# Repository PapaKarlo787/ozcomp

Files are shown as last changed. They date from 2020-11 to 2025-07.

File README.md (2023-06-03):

OzComp
======

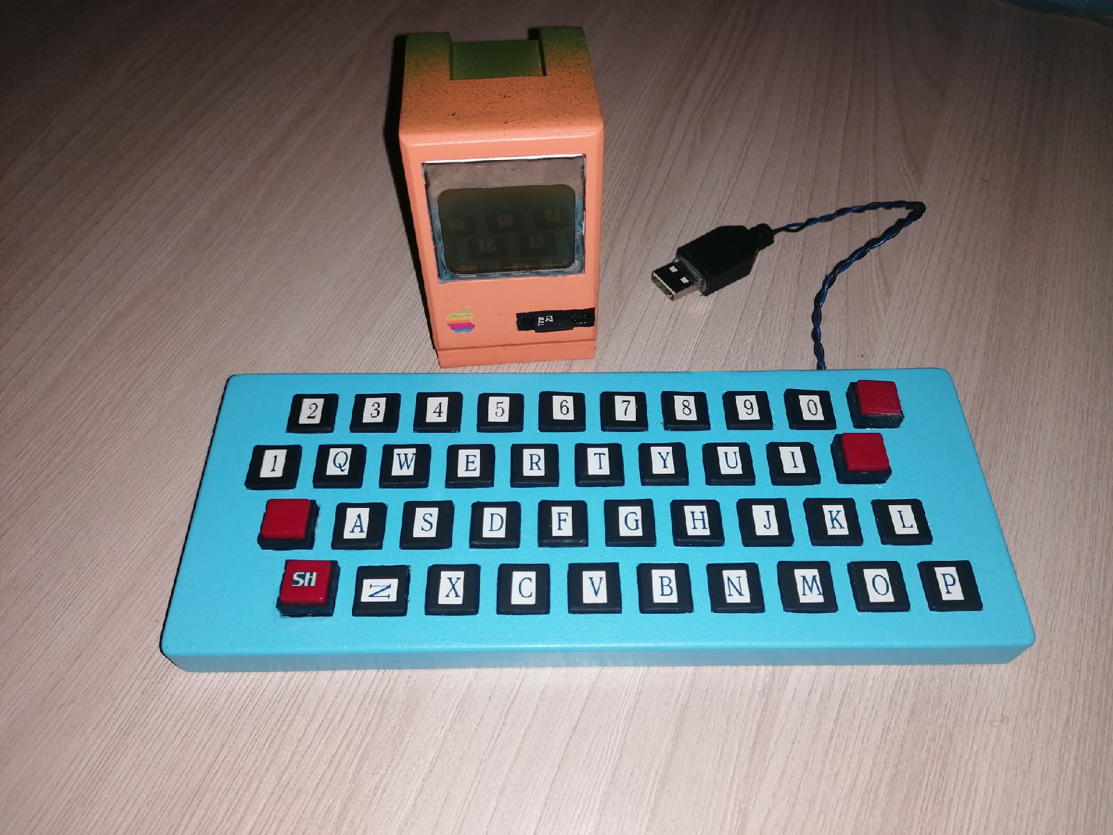
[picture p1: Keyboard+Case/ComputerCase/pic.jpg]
title


### Общее описание

Мы создаем компьютер на базе Arduino с удобными инструкциями, которые позволяют просто общаться с устройствами,
не используя их интерфейсы, не зная ничего о их протоколах и интерфейсах, что сокращает размер исходного кода.
Так же наш проект расширяет возможности Arduino. Теперь ей доступно около 2 Гб (не больше) оперативной памяти,
которая представлена в виде FLASH-памяти на SD карте. Так же имеется теоретическая (пока нет утилит) возможность,
не прибегая к стороннему программированию (программатор, компьютер для загрузки прошивки и т.д.), писать программы,
которые будут работать на нашем компьютере. Помимо прочего, наш проект устраняет скорый износ внутренней FLASH-памяти
(например при частой смене программного обеспечения) и последующую негодность платы. Это происходит за счет наличия внешнего подключения SD карты.

Ниже дано краткое описание системы команд, регистров и архитектуры в целом.
+ По 16 регистров с именами R0-R15 для плавающей арифметики и для целых чисел.
+ Системные регистры в количестве 16 штук, сейчас используются 3 - для указателя на инструкцию, указателя на вершину стека и для флагов состояния.
+ Операции для чисел с плавающей запятой это арифметические, стековые и операции копирования (MOV), их имена предворяются знаком F (FADD, FMOV).
+ Все регистры 32-битные.

### Таблица распиновки
|Пин Arduino	| Пин устройства	|	Название устройства
|-:				|:-:				|:-
D2				| RST				|	Часы
D3				| CLK				|	Клавиатура
D4				| MOSI				|	Экран
D5				| DC				|	Экран
D6				| CE				|	Экран
D7				| RST				|	Экран
D8				| DATA				|	Клавиатура
D9				| CLK				|	Экран
D10				| CS				|	SD
D11				| MOSI				|	SD
D12				| MISO				|	SD
D13				| CLK				|	SD
A0				| DAT				|	Часы
A1				| R					|	RGB
A2				| CLK				|	Часы
A3				| +					|	Пьезо
A4				| G					|	RGB
A5				| B					|	RGB
A6				| C1				|	mini-jack
A7				| C2				|	mini-jack

### Память и системные регистры

+ Память реализована как SD-карта (в эмуляторе файл 'memory'). Программа стартует с нулевого байта.
+ SP это внутренний указатель на вершину стека, устанавливается в начале программы в значение равное объему памяти на SD карте.
+ IP это внутренний указатель на текущую инструкцию.
+ FLAGS это внутренний регистр состояния, состоит из 16 битов устанавливаемых автоматически при выполнении инструкций и 16 битов устанавливаемых
программно для задания состояния компьютеру.

#### Биты регистра флагов

|Номер	|Обозначение| Назначение
|-:		|:-:		|:-
0		| E			| Результат целочисленной арифметики дал значение 0
1		| L			| Результат целочисленной арифметики дал значение < 0
2		| G			| Результат целочисленной арифметики дал значение > 0
3		| I			| Отрисовка графических примитивов перетерла значение на экране
4		| Z			| Результат плавающей арифметики дал значение 0
5		| B			| Результат плавающей арифметики дал значение < 0
6		| A			| Результат плавающей арифметики дал значение > 0
7		| NI		| Отрисовка графических примитивов не перетерла значение на экране
8-15	| N/A		| Зарезервировано
16		| COLOR		| Задает цвет отрисовки графики
17		| RGBSOUND	| Подсвечивать светодиодами музыку 
18-31	| N/A		| Зарезервировано

### Экран

Экран - монохромный и имеет разрешение 84*48 пикселя, это 6 рядов по 84 колонки.
Каждый зажженый пиксель в колонке n от левого верхнего угла последовательно -
слева направо, сверху вниз, означает установленный бит сверху вниз n-го байта в памяти экрана.
Экран не позволяет узнать содержимое своей памяти, поэтому она хранится в памяти Arduino. 

### Клавиатура

Компьютер запускается только при наличии подключенной AT-совместимой клавиатуры (PS/2).

### Звуки

Звуковой источник - пьезо-пищалка, которая установлена на 17 пин Arduino.
Аудио код состоит из количества пар 16-битных чисел, частоты пищания и задержки.
Реально задержки нет, поскольку сигнал генерируется отдельным таймером Arduino.

### Обозначения

+ R - регистр
+ C - константа
+ L - метка
+ N/A - нет аргументов
+ M - ячейка памяти, запись вида [L, R1, R2, N \in {1, 2, 4}], где формула адреса такова L+R1+R2*N - слагаемые могут отсутствовать, синтаксически отделенные запятыми.

### Арифметические операции

|Название 	| Аргументы |	Описание
|-:			|:-:		|:-
ADD 		| R/(R,C)	| 	Сложение
SUB 		| R/(R,C)	| 	Вычитание
MUL 		| R/(R,C)	| 	Умножение
DIV 		| R/(R,C)	| 	Деление
MOD		 	| R/(R,C)	| 	Остаток от деления
POW			| R/(R,C)	| 	Возведение в степень
CMP			| R/(R,C)	| 	Изменить флаги вычитанием
TEST		| R			| 	Изменить флаги сравнением с нулем

### Логические операции

|Название 	| Аргументы |	Описание
|-:			|:-:		|:-
AND 		| R/(R,C)	|	Побитовое И целых частей операндов
OR  		| R/(R,C)	|	Побитовое ИЛИ целых частей операндов
XOR 		| R/(R,C)	|	Побитовое исключающее ИЛИ целых частей операндов
SHR 		| R/(R,C)	|	Битовый сдвиг вправо
SHL 		| R/(R,C)	|	Битовый сдвиг влево

***Общий пример для этих групп команд.***

+ ADD R0, R1
+ ADD R0, 1

### Переходы

|Название 			| Аргументы |	Описание
|-:					|:-:		|:-
JMP					| L			| 	Безусловный переход
J{E,G,L,I,A,B,Z,...}| L			| 	Условный переход по E, G, L
LOOP				| L			| 	Условный переход пока R14 больше 0
CALL				| L			| 	Безусловный переход с сохранением IP в стек 
RET					| N/A		| 	Извлечение IP из стека

***Общий пример для этой группы команд.***

+ JNE my_label
+ CALL my_func
+ RET

### Работа со стеком

|Название 	| Аргументы |	Описание
|-:			|:-:		|:-
PUSH		| R 		|	Положить на стек
POP			| R			|	Снять со стека
FPUSH		| R			|	Положить на стек флоатовское значение
FPOP		| R			|	Снять со стека флоатовское значение

***Примеры***

+ PUSH R0
+ FPOP R1

### Экран, клавиатура и динамик

|Название 	| Аргументы |	Описание
|-:			|:-:		|:-
FPRINT 		| (R,L) 	| 	Печать числа с плавающей запятой
LPRINT 		| (R,L) 	| 	Печать нуль-терминированной строки
PRINT		| (R,L) 	| 	Печать целого числа
SCUR		| R/R, C/C 	| 	Установка курсора на позицию X, Y
SEND		| (R,C)		| 	Отправка байта на экран в текущую позицию курсора
DRAW		| L			| 	Отправить 504 байта в память экрана из памяти с адреса L
GKEY		| N/A		| 	Получить символ клавиатуры в регистре R15, 0 если нет
SCOL  		| C 		| 	Установить цвет рисуемого изображения (0 или не 0 для монохромного экрана)
PLAY  		| L 		| 	Начать циклическое проигрывание музыки
NPLAY 		| N/A		| 	Завершить проигрывание музыки
RGB 		| R/R/R		| 	Установить цвет светодиодов
RGB 		| C/C/C		| 	Установить цвет светодиодов
MLS 		| N/A		| 	Узнать количество милисекунд, пройденных с запуска, в R12
MCS 		| N/A		| 	Узнать количество микросекунд, пройденных с запуска, в R12
RPIX 		| R/(R,C)	| 	Реверс нескольких подряд идущих столбцов экрана

***Примеры***

+ PRINT my_str
+ IPRINT R0
+ SETC R0, R5
+ SETC 10, 20
+ SEND R0 (<256)
+ SEND 85
+ GKEY

### Макрокоманды MCASM

|Название 	| Аргументы 	|	Описание
|-:			|:-:			|:-
DD			| C1, C2, ...	|	Создать несколько 32-битных чисел
DW			| C1, C2, ...	|	Создать несколько 16-битных чисел
DB			| C1, C2, ...	|	Создать несколько 8-битных чисел, (строки тоже)
DF			| C1, C2, ...	|	Создать несколько 32-битных чисел с плавающей запятой
TIMES 		| CMD ARGS  N 	|	Повторить команду CMD N раз

***Примеры***

+ DD -3, 100500, 0xffffffff
+ DB 10, 12, 255, "HELLO WORLD!"
+ DF 3.1415926535, 2.718281828
+ TIMES CALL INC 10

### Другие

|Название 	| Аргументы 	|	Описание
|-:			|:-:			|:-
MOV 		| R/(R,C,M),M/R | 	Перемещение данных во float
MOVB		| R/M,M/R 		|	Перемещение байтов в ячейки памяти
INT			| R				|	Округление
DELAY		| (R,C)			|	Задержка в милисекундах
RND			| N/A			| 	Случайное целое в промежутке [0, 1024], результат в R13
ICVTF 		| R/R 			| 	Конвертация float в int
FCVTI 		| R/R 			| 	Конвертация int в float
GTM 		| R/R/R			| 	Получить время RTC
STM 		| (R/R/R,C/C/C)	| 	Установить время RTC
MZER 		| (R,C)/(C,C)	| 	Занулить фиксированное количество байт по указателю

***Примеры***

+ MOV [my_var], R0
+ MOV R0, [my_var, R1]
+ INT R0
+ DELAY R1
+ DELAY 100
+ RND

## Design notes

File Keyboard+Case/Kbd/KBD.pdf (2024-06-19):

Лист1

Страница 1

Q ES W F1 E F2 R F3 T F4 Y F5 U F6 I F7 O F8 P F9
q TB w | e | r | t | y | u | i ( o ) p BS
A 1 S 2 D 3 F 4 G 5 H 6 J 7 K 8 L 9 ` 0 a ! s @ d # f $ g % h ^ j & k * l ↑ ~ PS Z [ X ] C \ V ; B ' N - M = , DL . PU / PD
z { x } c | v : b “ n _ m + < | > ↓ ? →
Shift Ctrl Alt | ___ | Alt Ctrl Caps ENT

Q ES W F1 E F2 R F3 T F4 Y F5 U F6 I F7 O F8 P F9
q TB w | e | r | t | y | u | i ( o ) p BS
A 1 S 2 D 3 F 4 G 5 H 6 J 7 K 8 L 9 ` 0 a ! s @ d # f $ g % h ^ j & k * l ↑ ~ PS Z [ X ] C \ V ; B ' N - M = , DL . PU / PD
z { x } c | v : b “ n _ m + < | > ↓ ? →
Shift Ctrl Alt | ___ | Alt Ctrl Caps ENT

Q ES W F1 E F2 R F3 T F4 Y F5 U F6 I F7 O F8 P F9
q TB w | e | r | t | y | u | i ( o ) p BS
A 1 S 2 D 3 F 4 G 5 H 6 J 7 K 8 L 9 ` 0 a ! s @ d # f $ g % h ^ j & k * l ↑ ~ PS Z [ X ] C \ V ; B ' N - M = , DL . PU / PD
z { x } c | v : b “ n _ m + < | > ↓ ? →
Shift Ctrl Alt | ___ | Alt Ctrl Caps ENT

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

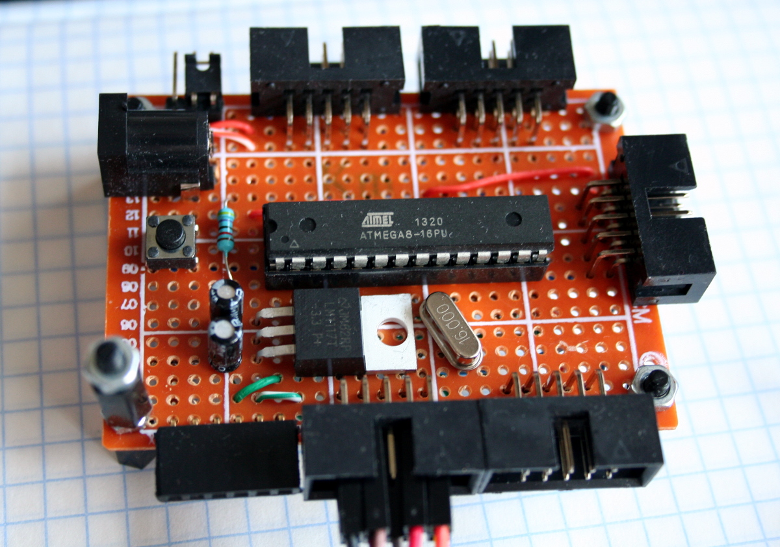
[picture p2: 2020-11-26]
docs/ATmega8 + PCD8544_ работа с графическим дисплеем от телефонов Nokia 5110_3310_files/atmega8.jpg

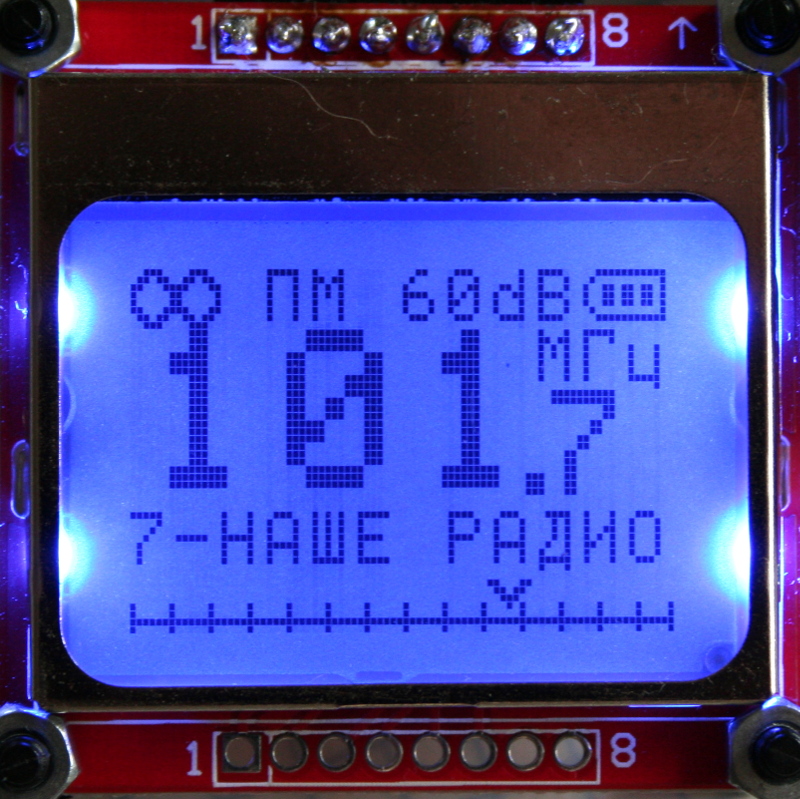
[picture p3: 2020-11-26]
docs/ATmega8 + PCD8544_ работа с графическим дисплеем от телефонов Nokia 5110_3310_files/cover1.jpg

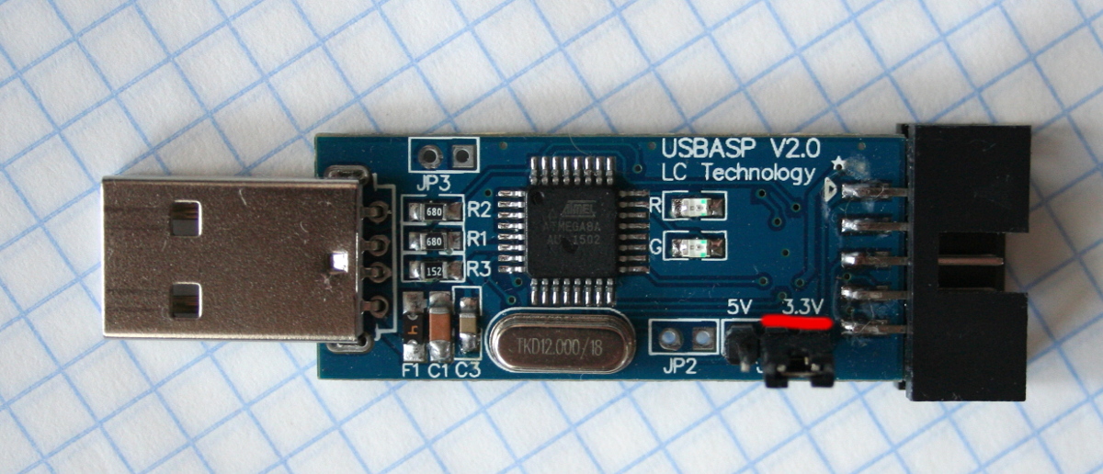
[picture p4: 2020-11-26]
docs/ATmega8 + PCD8544_ работа с графическим дисплеем от телефонов Nokia 5110_3310_files/usbasp.jpg

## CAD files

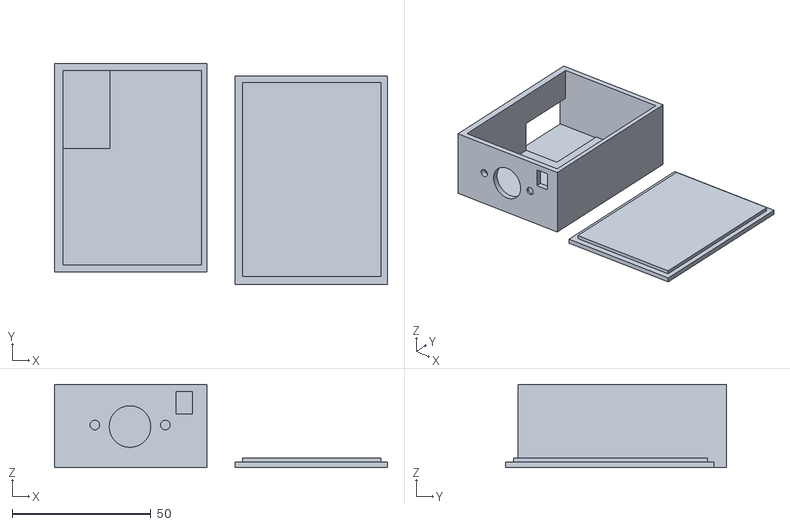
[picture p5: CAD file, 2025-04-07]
Keyboard+Case/CompExtension case.stl
120.0 x 79.5 x 30.0

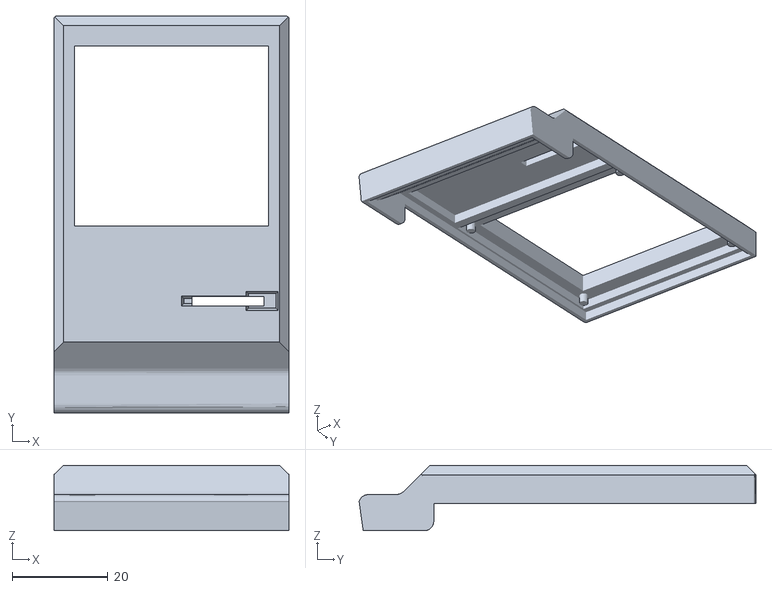
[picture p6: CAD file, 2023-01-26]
Keyboard+Case/ComputerCase/Крышка.stl
49.0 x 82.7 x 13.6

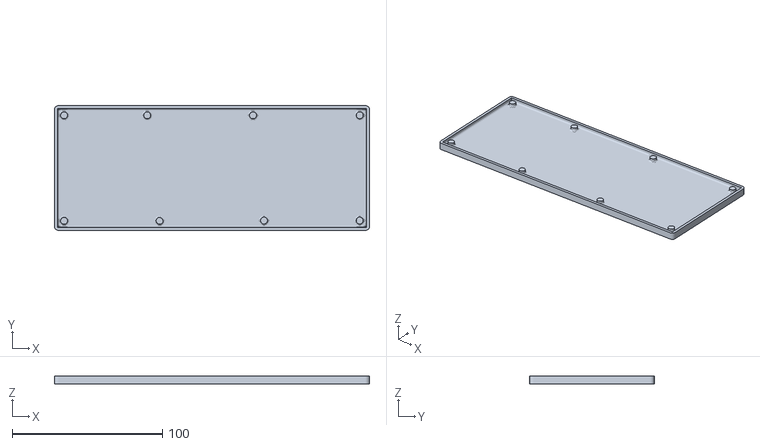
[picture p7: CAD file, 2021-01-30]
Keyboard+Case/KeyboardCase/K-n2.stl
209.5 x 82.9 x 5.10

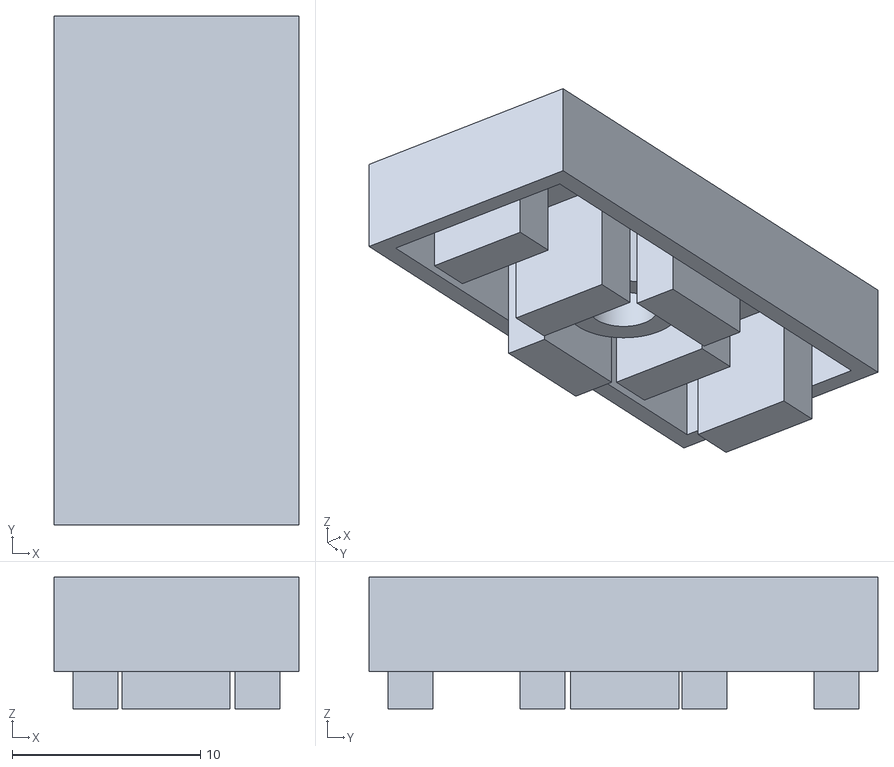
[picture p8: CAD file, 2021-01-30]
Keyboard+Case/KeyboardCase/Keycaps/keycap-long.stl
13.0 x 27.0 x 7.00

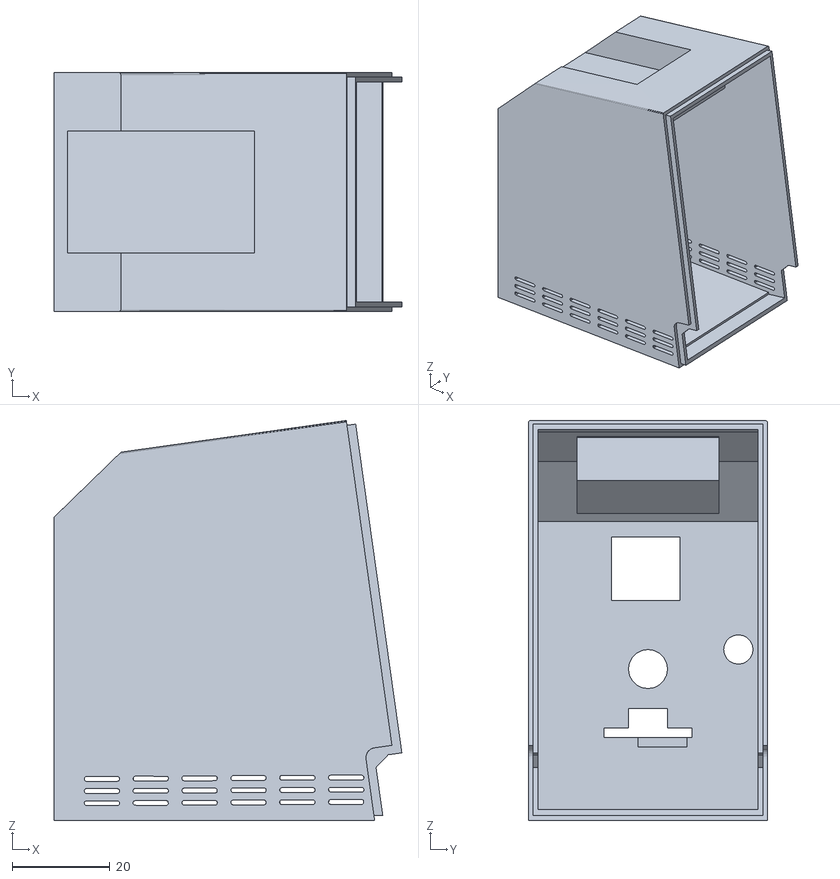
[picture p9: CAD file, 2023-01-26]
Keyboard+Case/ComputerCase/Корпус.stl
71.2 x 49.0 x 81.9

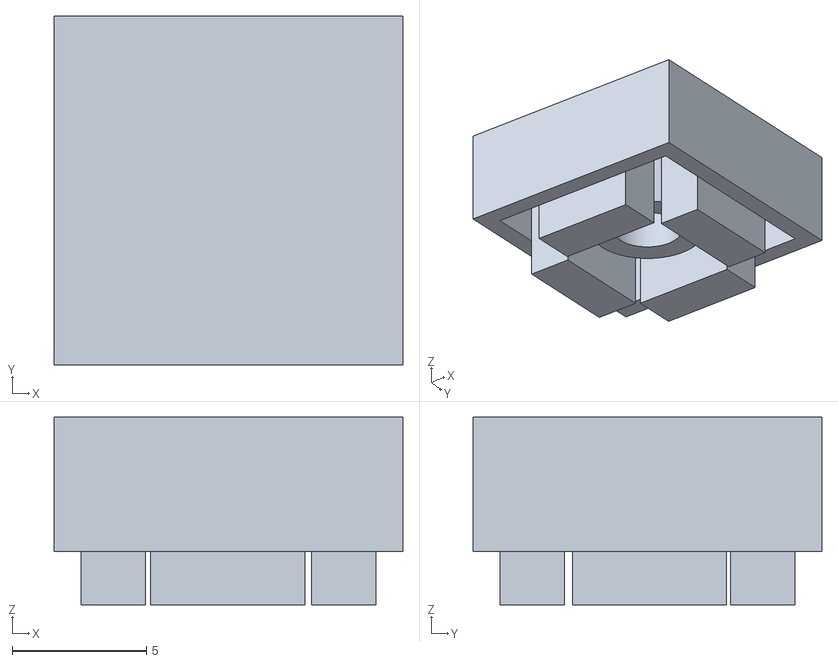
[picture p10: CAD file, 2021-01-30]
Keyboard+Case/KeyboardCase/Keycaps/keycap.stl
13.0 x 13.0 x 7.00

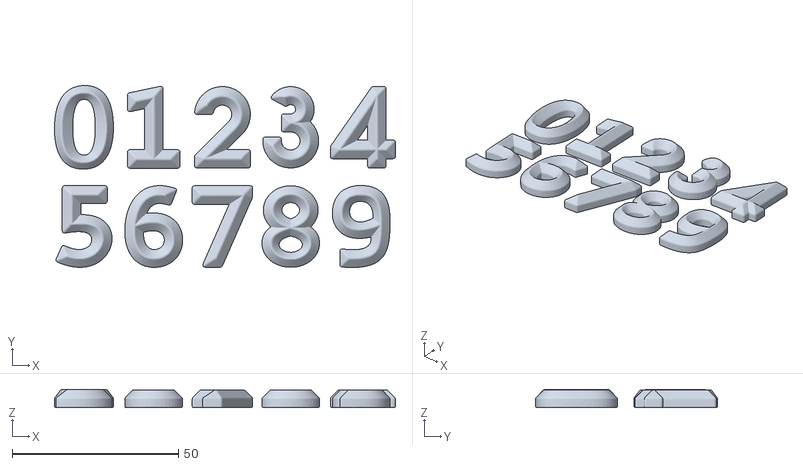
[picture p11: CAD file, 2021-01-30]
Keyboard+Case/KeyboardCase/numbers.stl
102.5 x 54.7 x 5.41

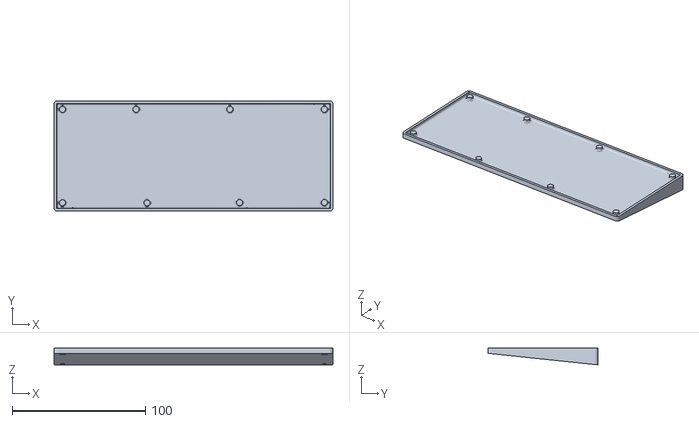
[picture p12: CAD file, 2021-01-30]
Keyboard+Case/KeyboardCase/K-n1.stl
209.5 x 82.9 x 12.6

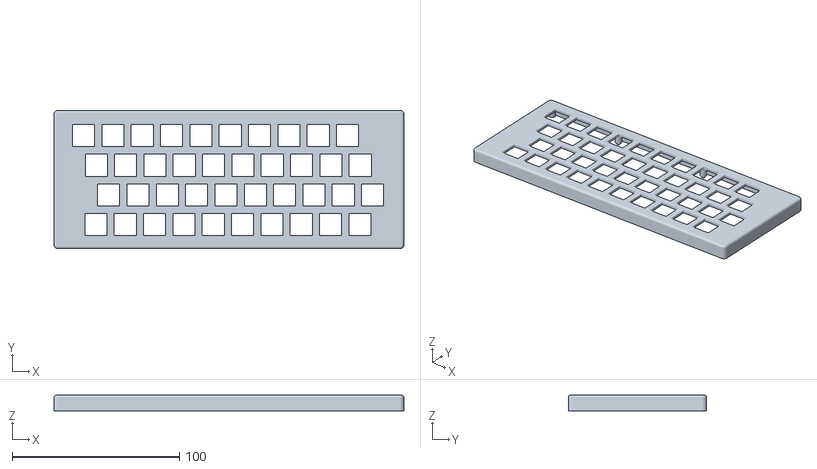
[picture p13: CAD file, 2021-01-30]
Keyboard+Case/KeyboardCase/k-verh.stl
209.5 x 82.9 x 9.50

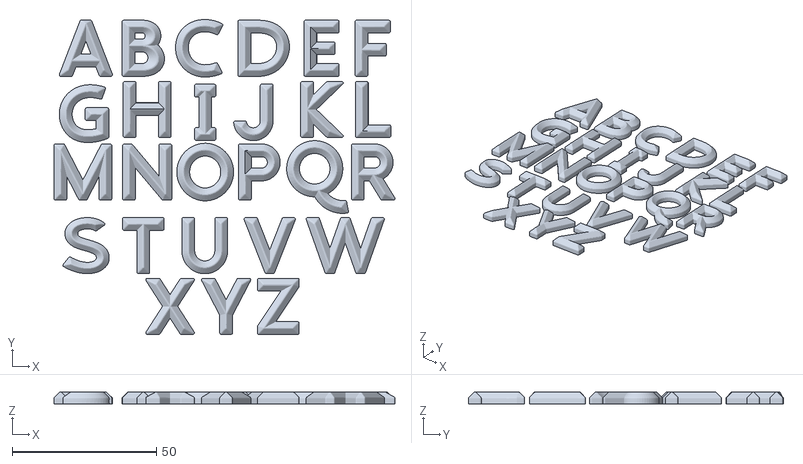
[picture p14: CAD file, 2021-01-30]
Keyboard+Case/KeyboardCase/Letters.stl
118.0 x 109.0 x 4.24

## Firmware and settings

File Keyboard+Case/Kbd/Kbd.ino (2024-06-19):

#include <ps2dev.h>

PS2dev kbd(14, 13);
const PROGMEM int P[] = {15, 16, 2, 3, 4, 5, 6, 7}; // пины строк
const PROGMEM int M[] = {8, 9, 10, 11, 12};   // пины столбцов
const PROGMEM uint8_t led_pins[4] = {A2, A0, A1, A3};

const PROGMEM char sym_tables [4][5][8] = {
  { // Red
    {'Q', 'W', 'A', 'S', 'Z', 'X', 0x02, 0x03}, // shift, ctrl
    {'E', 'R', 'D', 'F', 'C', 'V', 0x04, 0x05}, // alt, apple
    {'T', 'Y', 'G', 'H', 'B', 'N', 0x20, 0x07}, // space, lamp
    {'U', 'I', 'J', 'K', 'M', ',', 0x14, 0x13}, // ralt, rctrl
    {'O', 'P', 'L', '`', '.', '/', 0x12, 0x0A}  // rshift, enter
  }, 
  { // Blue
    {'q', 'w', 'a', 's', 'z', 'x', 0x02, 0x03},
    {'e', 'r', 'd', 'f', 'c', 'v', 0x04, 0x05},
    {'t', 'y', 'g', 'h', 'b', 'n', 0x20, 0x07},
    {'u', 'i', 'j', 'k', 'm', '<', 0x14, 0x13},
    {'o', 'p', 'l', '~', '>', '?', 0x12, 0x0A}
  },
  { // Green
    {0x01, 0x15, '1', '2',  '[',  ']', 0x02, 0x03}, 
    {0x16, 0x17, '3', '4', '\\',  ';', 0x04, 0x05},
    {0x18, 0x19, '5', '6', '\'',  '-', 0x20, 0x07},
    {0x1A, 0x1B, '7', '8',  '=', 0x7F, 0x14, 0x13}, // del
    {0x1C, 0x1D, '9', '0', 0x0B, 0x0C, 0x12, 0x0A}  // p_up, p_dn
  }, 
  { // Black
    {0x09, 0x00,  '!',  '@',  '{',  '}', 0x02, 0x03}, // tab
    {0x00, 0x00,  '#',  '$',  '|',  ':', 0x04, 0x05},
    {0x00, 0x00,  '%',  '^',  '"',  '_', 0x20, 0x07},
    {0x00,  '(',  '&',  '*',  '+', 0x0E, 0x14, 0x13}, // left
    { ')', 0x08, 0x0D, 0x06, 0x0F, 0x10, 0x12, 0x0A}  // backspace, up, printscr, down, right
  }
};

uint64_t old_keys = 0;
uint8_t leds;
char last_key = 0;
uint32_t time = 0;
uint8_t rep_time = 0;
uint8_t table_index = 0;

void setup() {
  for (int i = 0; i < 8; i++) {  // выставляем пины строк на выход, столбцов на вход
    pinMode(pgm_read_byte(&P[i]), OUTPUT);
    digitalWrite(pgm_read_byte(&P[i]), HIGH);
  }
  for (int i = 0; i < 5; i++) {  // выставляем пины строк на выход, столбцов на вход
    pinMode(pgm_read_byte(&M[i]), INPUT_PULLUP);
  }
  table_index = 0;
  digitalWrite(pgm_read_byte(&led_pins[table_index]), 1);
}

void loop() {
  if (millis() - time > 50) {
    uint64_t cur_keys = GetKey();             // опрашиваем клавиатуру
    uint64_t changes = old_keys ^ cur_keys;
    for (byte p = 0; p < 8; p++) {
      for (byte m = 0; m < 5; m++) {
        uint64_t bit = ((uint64_t)1 << ((m << 3) + p)); 
        if (changes & bit)
          if (cur_keys & bit) {
            rep_time = 11;
            last_key = pgm_read_byte(&sym_tables[table_index][m][p]);
            kbd.write(last_key);
            if (last_key == 0x07) {
              table_index = (table_index + 1) & 3;
              digitalWrite(pgm_read_byte(&led_pins[table_index]), 1);
              digitalWrite(pgm_read_byte(&led_pins[(table_index + 1) & 3]), 0);
              digitalWrite(pgm_read_byte(&led_pins[(table_index + 2) & 3]), 0);
              digitalWrite(pgm_read_byte(&led_pins[(table_index + 3) & 3]), 0);
            }
          }
          else {
            if (last_key == pgm_read_byte(&sym_tables[table_index][m][p]))
              last_key = 0;
            kbd.write(pgm_read_byte(&sym_tables[table_index][m][p]) | 0x80);
          }
      }
    }
    time = millis();
    old_keys = cur_keys;
    if (last_key) {
      rep_time--;
      if (!rep_time) {
        rep_time = 2;
        kbd.write(last_key);
      }
    }
  }
  kbd.keyboard_handle(&leds);
}

uint64_t GetKey() {
  uint64_t res = 0;
  for (byte p = 0; p < 8; p++) {    // последовательно выставляем по одной строке в LOW
    digitalWrite(pgm_read_byte(&P[p]), LOW);
    for (byte m = 0; m < 5; m++) {  // и считываем столбцы вылавнивая где LOW происходит
      if (!digitalRead(pgm_read_byte(&M[m]))) {
        res |= (uint64_t)1 << ((m << 3) + p);             // считываем соотвествующий символ для комбинации столбца и строки
      }
    }
    digitalWrite(pgm_read_byte(&P[p]), HIGH);       // возвращем строку в HIGH и крутим дальше
  }
  return res;
}

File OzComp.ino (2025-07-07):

#include <Arduino.h>
#include <sd_raw.h>
#include <PS2Keyboard.h>
#include <MyScreen.h>
#include <iarduino_RTC.h>

#define RealScreen NokiaScreen

#include "arch/arch.h"


void setup() {
  Serial.begin(9600);
  begin();
  sd_raw_info info;
  sd_raw_get_info(&info);
  sp = info.capacity;
}

void loop() {
  void (*f) (void) = pgm_read_word(&comms[read_()]);
  (*f)();
  fill_mbuffer();
}

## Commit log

2021-02-12 work on arduino
    [Detal1.stl, Detal2.stl, K-n1.stl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]
2021-02-16 arduino works
2021-02-20 fixes after changing structure
    [OzComp.ino]
2021-10-01 screen updated to console
    [Detal1.stl, Detal2.stl, K-n1.stl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]
2022-03-03 bugs around flashing fixed
    [Detal1.stl, Detal2.stl, K-n1.stl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]
2022-03-11 sound works again
    [Detal1.stl, Detal2.stl, K-n1.stl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]
2022-03-22 yeee no rush resourse errors!))
    [OzComp.ino, system_functions.h]
2022-05-12 fixed flags added ld-st
    [system_functions.h]
2023-01-26 new box
    [Detal1.stl, Detal2.stl, Корпус.stl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]
2024-06-18 keyboard works
    [KBD.xlsx]
2024-06-19 kbd led is on
2024-06-19 keys fixed
    [KBD.xlsx]
